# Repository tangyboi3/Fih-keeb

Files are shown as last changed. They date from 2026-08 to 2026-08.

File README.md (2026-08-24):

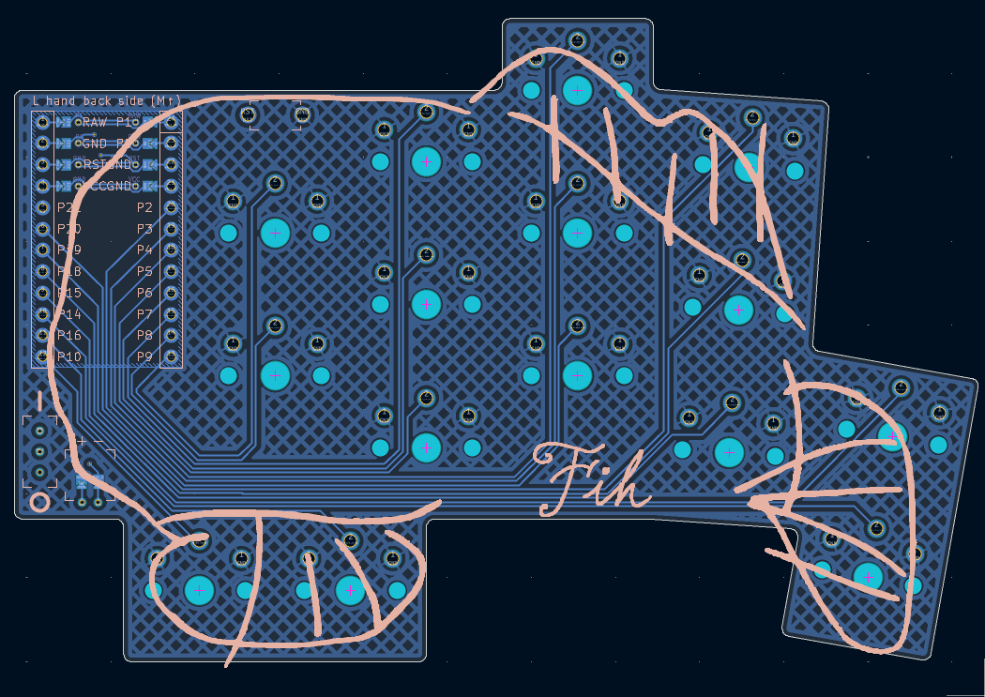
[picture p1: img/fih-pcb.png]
pcb


# Fih keeb
Fih keeb. 23332+2, very staggered, made using ergogen.

## BOM
| Name | Qt | Notes|
| :--- | :---: | :--- |
| Fih pcbs | 2 | gerbers [here](./pcb/gerbers) |
| nice!nanos or clones | 2 | i used [these](https://www.aliexpress.us/item/3256806824240477.html) |
| female headers | 48 | make sure you get the shortest ones, ph3.5. [ali](https://www.aliexpress.us/item/3256806227209544.html) |
| 301230 LiPos | 2 | any size that can fit under the n!n will work, i used [these](https://www.aliexpress.us/item/3256809270469725.html) |
| JST PH 2.0 connectors | 2 | [ali](https://www.aliexpress.us/item/3256804769340392.html) |
| choc v1 or v2 switches and keycaps | 30 | duh |
| SS12D00 power switches | 2 | [ali](https://www.aliexpress.us/item/3256810241242670.html) |
| TS-1136 reset buttons | 2 | make sure you get the DIP version. [ali](https://www.aliexpress.us/item/3256801442870232.html) |
| rubber feet | 8 | [ali](https://www.aliexpress.us/item/3256805129083590.html) |
> note: solder the jumpers on the BACK of the pcb relative to your parts. the n!n silkscreen has a reminder.

## firmware
[here](https://github.com/tangyboi3/zmk-keyboard-fih/)

## thanks
thanks to mrzealot for [ergogen](https://ergogen.ceoloide.com/), ceoloide for their fork and [footprints](https://github.com/ceoloide/ergogen-footprints/), genteure for the neat [zmk shield wizard](https://shield-wizard.genteure.com/), [zmk](https://v0-3-branch.zmk.dev/) itself for the firmware, the [hummingbird](https://github.com/PJE66/hummingbird), [berylline](https://github.com/jcmkk3/trochilidae#berylline), [pueo](https://github.com/grassfedreeve/pueo/), [i'iwi](https://github.com/grassfedreeve/iiwi), and [fitis](https://github.com/weteor/Fitis) keyboards for inspiration, and @car_kaboomer on discord for all the help.

## todo
get pictures

maybe make a case

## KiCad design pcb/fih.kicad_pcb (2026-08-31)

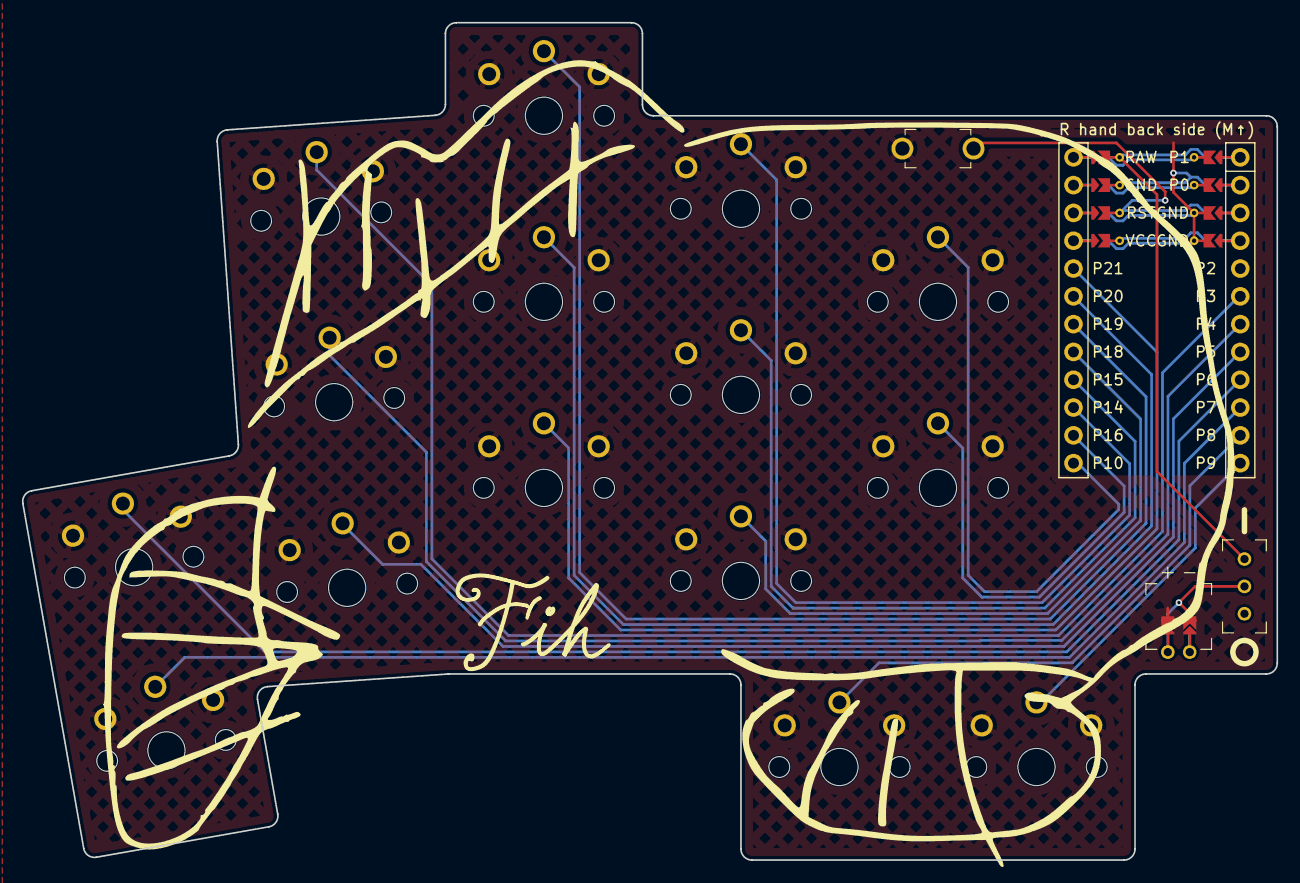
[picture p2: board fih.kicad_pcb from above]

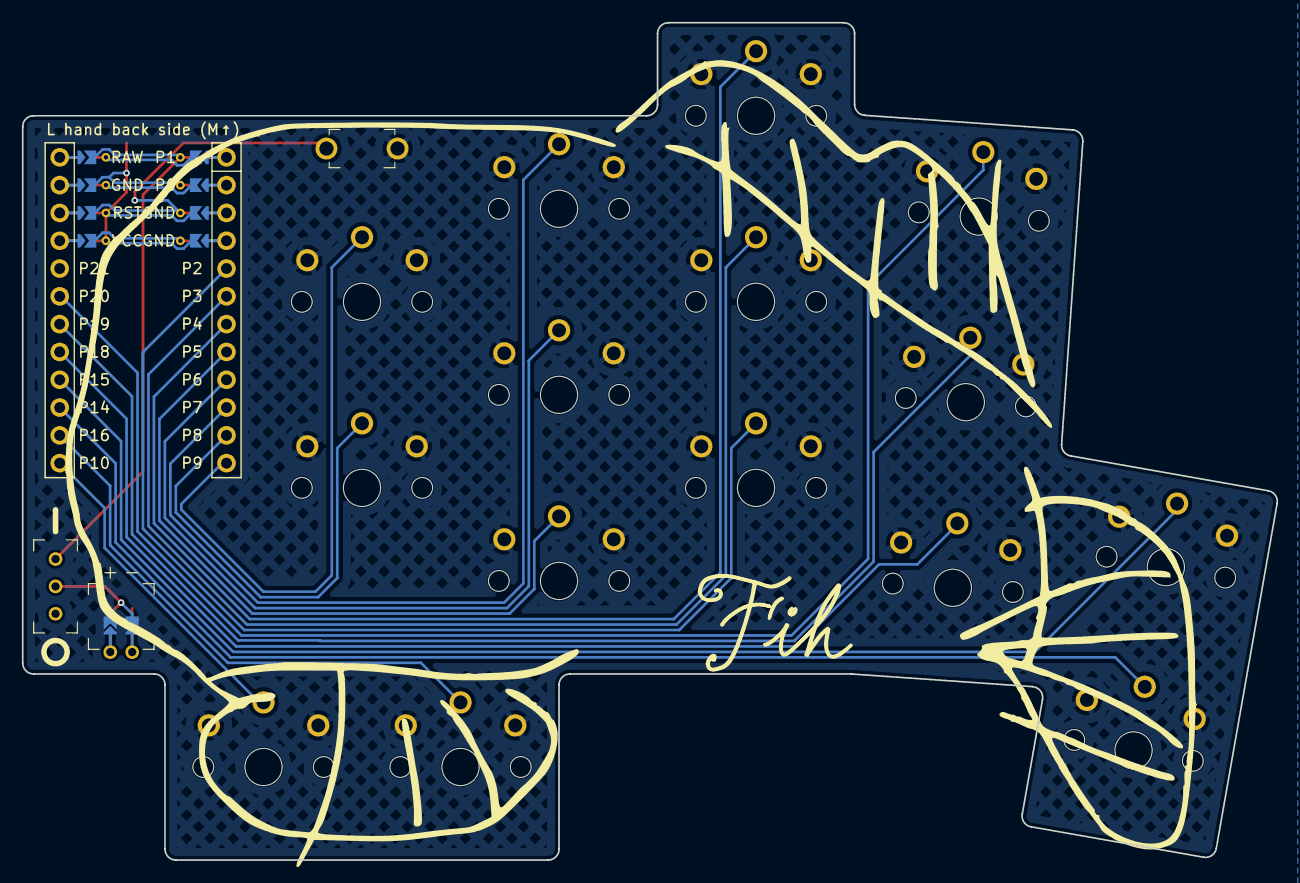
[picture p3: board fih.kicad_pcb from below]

Board: 2 copper layers, 114.6 x 76.5 mm, 19 parts (15 on the bottom side), 21 nets.

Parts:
MCU1: mcu_supermini_nrf52840
PWR1: SS12D00
RST1: TS1236
S1, S2, S3, S4, S5, S6, S7, S8, S9, S10, S11, S12, S13, S14, S15: switch_choc_v1_v2
XX1: JSTPH2

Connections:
BAT_P: PWR1.BAT_P, XX1.BAT_P
GND: MCU1.103, MCU1.104, MCU1.123, RST1.GND, S1.1, S2.1, S3.1, S4.1, S5.1, S6.1, S7.1, S8.1, S9.1, S10.1, S11.1, S12.1, S13.1, S14.1, S15.1, XX1.BAT_N
JST1: XX1.1, XX1.21, XX1.31
JST2: XX1.2, XX1.22, XX1.32
RAW: MCU1.124, PWR1.RAW
RST: MCU1.122, RST1.RST
matrix_index_bottom: MCU1.17, S9.2
matrix_index_home: MCU1.16, S10.2
matrix_index_top: MCU1.15, S11.2
matrix_inner_home: MCU1.14, S12.2
matrix_inner_top: MCU1.13, S13.2
matrix_middle_bottom: MCU1.20, S6.2
matrix_middle_home: MCU1.19, S7.2
matrix_middle_top: MCU1.18, S8.2
matrix_pinky_bottom: MCU1.10, S1.2
matrix_pinky_home: MCU1.9, S2.2
matrix_ring_bottom: MCU1.8, S3.2
matrix_ring_home: MCU1.7, S4.2
matrix_ring_top: MCU1.6, S5.2
thumbs_reachy: MCU1.12, S15.2
thumbs_tucky: MCU1.11, S14.2
